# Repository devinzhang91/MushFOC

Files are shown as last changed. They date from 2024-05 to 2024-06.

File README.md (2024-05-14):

# MushFOC
A simple FOC with stm32 hal project. With PCB schematic and Python.
Reference from [CawFOC](https://github.com/GUAIK-ORG/CawFOC) and [DengFOC](https://github.com/ToanTech/DengFOC_Lib)

## STM32
- STM32G0 series, Flash 64KB and Ram 8KB.
- Control with I2C or UART (more?).
- HAL library.
- FREERTOS.

## PCB
- MCU: STM32G031F8
- Driver: DRV8313
- Current Sensor: INA180
- Angle Sensor: AS5600
- Reserve peripherals: SSD1306(OLED) MPU6050(Gyroscope)

## Python
- With smbus tools

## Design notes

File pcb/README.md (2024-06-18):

# MushFOC
A simple FOC with PCB project. 

There are some BUGs in TinyFoc_v1 SCH file, such as: 
- The direction of the LED is reversed.(BUT IT WORK!)

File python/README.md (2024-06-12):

# MushFOC
A simple FOC with stm32 hal project. Here are python control scripts. Using smbus packages.

-

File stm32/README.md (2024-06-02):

# MushFOC
A simple FOC with stm32 hal project.
- STM32G0 series, Flash 64KB and Ram 8KB.
- Control with I2C or UART (more?).
- HAL library.
- FREERTOS.

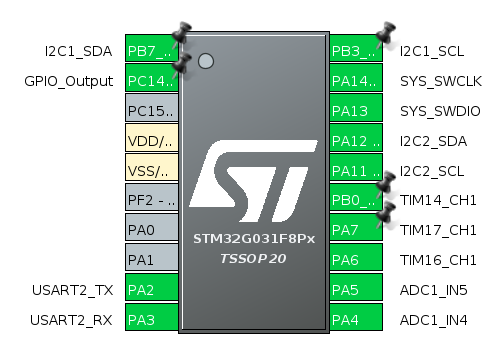
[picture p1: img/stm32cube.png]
stm32cubeMX


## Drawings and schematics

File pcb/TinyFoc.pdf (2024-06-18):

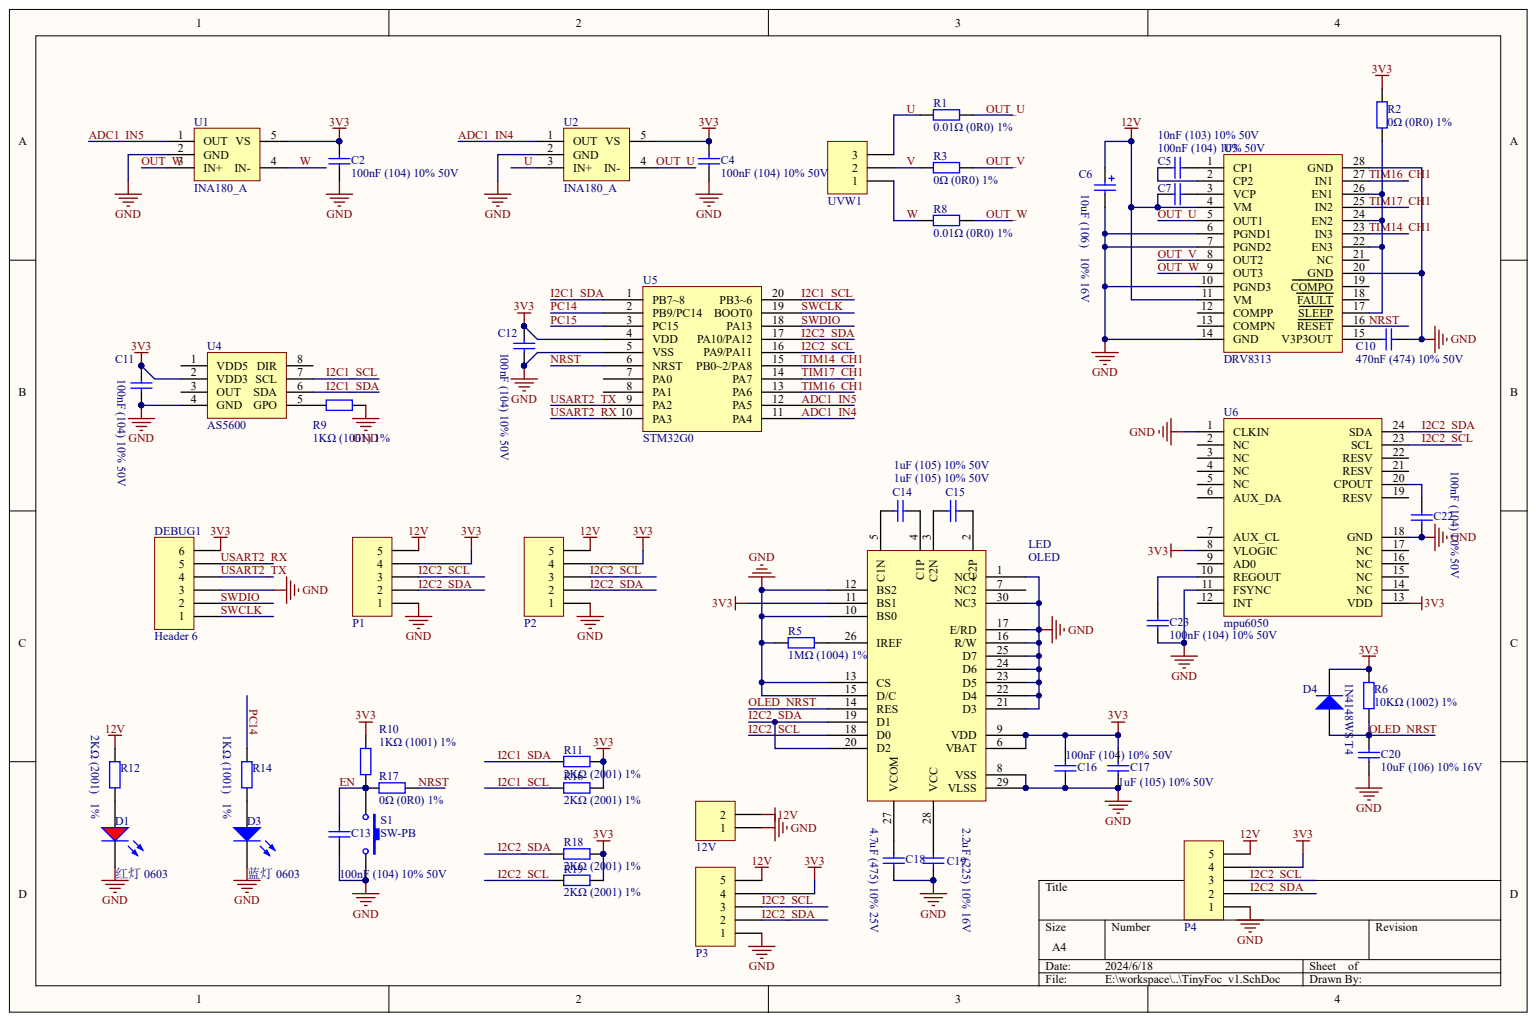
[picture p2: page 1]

OUT_V | 8

1 1
BS0 10

R5 | IREF 26

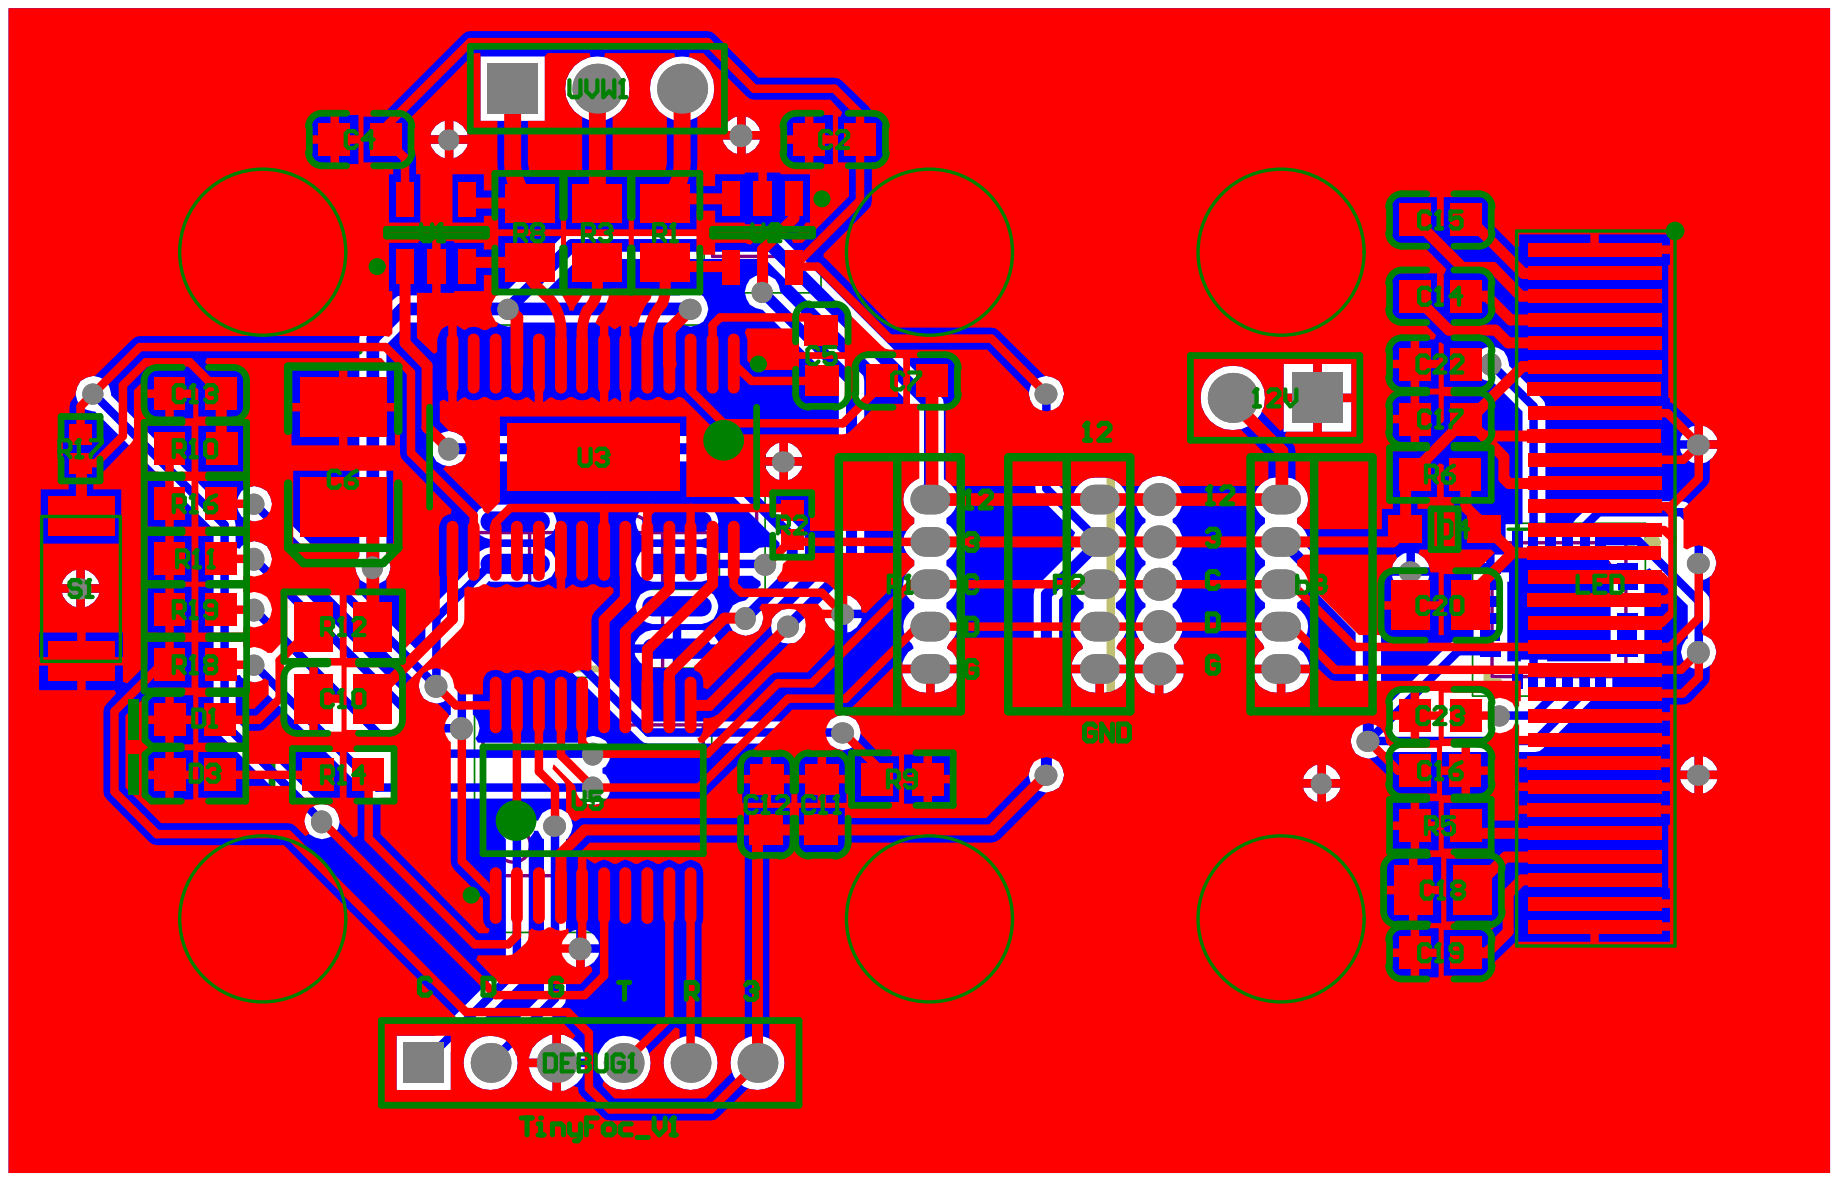
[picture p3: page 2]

Comment | Description | Designator | Footprint | LibRef | Quantity
Header 2 | 接插件 | 12V | HDR2X1_A | Header 2 | 1
100nF (104) 10% 50V | 贴片电容 | C2, C4, C7, C11, C12, C13, C16, C22, C23 | 0603_C | 0603 100nF (104) 10% 50V | 9
10nF (103) 10% 50V | 贴片电容 | C5 | 0603_C | 0603 10nF (103) 10% 50V | 1
10uF (106) ¡ À 1 0% 16V | 钽电容 | C6 | CASE-B_3528 | 3528 100uF (107) 10% 6.3V | 1
470nF (474) 10% 50V | 贴片电容 | C10 | 0805_C | 0805 470nF (474) 10% 50V | 1
1uF (105) 10% 50V | 贴片电容 | C14, C15, C17 | 0603_C | 0603 1uF (105) 10% 50V | 3
4.7uF (475) 10% 25V | 贴片电容 | C18 | 0805_C | 0805 4.7uF (475) 10% 25V | 1
2.2uF (225) 10% 16V | 贴片电容 | C19 | 0603_C | 0603 2.2uF (225) 10% 16V | 1
10uF (106) 10% 16V | 贴片电容 | C20 | 0805_C | 0805 10uF (106) 10% 25V | 1
红灯 0603 | 发光二极管 | D1 | 0603_LED_S1 | 0603 红灯 | 1
蓝灯 0603 | 发光二极管 | D3 | 0603_LED_S1 | 0603 蓝灯 | 1
1N4148WS T4 | 二极管 | D4 | SOD-323 | SOD-323 1N4148WS T4 | 1
Header 6 | 接插件 | DEBUG1 | HDR6X1_A_2.0 | Header 6 | 1
OLED | OLED显示屏12864 | LED | OLED_pin30 | OLED | 1
Header 5 | 接插件-1.27 | P1, P2, P3 | HDR5_1.27_A | Header 5 | 3
Header 5 | 接插件-1.27 | P4 | HDR5_1.27_B | Header 5 | 1
0.01Ω (0R0) ¡ À 1 % | 贴片电阻 | R1, R8 | 0805_R | 0805 0Ω (0R0) 1% | 2
0Ω (0R0) ¡ À 1 % | 贴片电阻 | R2, R17 | 0402_R | 0402 0Ω (0R0) 1% | 2
0Ω (0R0) ¡ À 1 % | 贴片电阻 | R3 | 0805_R | 0805 0Ω (0R0) 1% | 1
1MΩ (1004) ¡ À 1 % | 贴片电阻 | R5 | 0603_R | 0603 1MΩ (1004) 1% | 1
10KΩ (1002) ¡ À 1 % | 贴片电阻 | R6 | 0603_R | 0603 10KΩ (1002) 1% | 1
1KΩ (1001) ¡ À 1 % | 贴片电阻 | R9, R10, R14 | 0603_R | 0603 1KΩ (1001) 1% | 3
2KΩ (2001) ¡ À 1 % | 贴片电阻 | R11, R16, R18, R19 | 0603_R | 0603 2KΩ (2001) 1% | 4
2KΩ (2001) ¡ À 1 % | 贴片电阻 | R12 | 0805_R | 0805 2KΩ (2001) 1% | 1
SW-PB | 微动开关 | S1 | SW_PB2_3*5 | SW-PB | 1
INA180_A | 电流检测 | U1, U2 | SOT23 | INA180_A | 2
DRV8313 | 无刷电机驱动芯片 | U3 | TSSOP-28p | DRV8313 | 1
AS5600 | 磁编码器 | U4 | SOP-8N | AS5600 | 1
STM32G0 | STM32单片机20引脚 | U5 | STM8S103 | STM32G0 | 1
mpu6050 | | U6 | QFN50P400X400X80_HS-25N | mpu6050 | 1
Header 3 | 接插件 | UVW1 | HDR3X1_A | Header 3 | 1

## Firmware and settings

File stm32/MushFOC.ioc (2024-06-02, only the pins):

Mcu.UserName=STM32G031F8Px
PA13.Signal=SYS_SWDIO
PA14-BOOT0.Signal=SYS_SWCLK
PA2.Signal=USART2_TX
PA3.Signal=USART2_RX
PA4.Signal=ADC1_IN4
PA5.Signal=ADC1_IN5
PA6.Signal=S_TIM16_CH1
PA7.Signal=S_TIM17_CH1
PB1.Signal=S_TIM14_CH1
PB6.Signal=I2C1_SCL
PB7.Signal=I2C1_SDA

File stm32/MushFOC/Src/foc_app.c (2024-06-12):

/*
 * @Author: devinzhang@gmail.com
 * @Date: 2024-05-03 15:14:43
 * @LastEditors: DevinZhang91
 * @LastEditTime: 2024-05-03 15:14:43
 * @Description: Modified according to CAW FOC project https://github.com/GUAIK-ORG/CawFOC
 */
#include <foc_app.h>
#include "usart.h"

#define _PI 3.141592653589793f
uint8_t buff[16];

void FOC_APP_Init(FOC_APP_T *hfoc_app){
	hfoc_app->target_angle = 0.0f;
	hfoc_app->target_velocity = 0.0f;
	hfoc_app->target_current = 0.0f;
	hfoc_app->max_output_angle = FOC_DEFAULT_MAX_OUTPUT_ANGLE;
	hfoc_app->max_zero_angle = FOC_DEFAULT_MAX_ZERO_ANGLE;
	hfoc_app->min_zero_angle = FOC_DEFAULT_MIN_ZERO_ANGLE;
	hfoc_app->max_output_velocity = FOC_DEFAULT_MAX_OUTPUT_VELOCITY;
	hfoc_app->max_output_current = FOC_DEFAULT_MAX_OUTPUT_CURRENT;
	hfoc_app->accumulated_heat_threshold_roatio = FOC_DEFAULT_ACCUMULATED_THRESHOLD_ROATIO;
}

void FOC_CheckCurrentOverflow(){

}

// 测试闭环速度控制
void Foc_TestVelocity(FOC_T *hfoc,
					  LOWPASS_FILTER_T *hfilter_velocity,
					  PID_T *hpid_velocity,
					  float target_velocity) {
  float sensor_velocity = hfoc->Sensor_GetVelocity();
  sensor_velocity = LOWPASS_FILTER_Calc(hfilter_velocity, hfoc->dir * sensor_velocity);
  PID_Set(hpid_velocity, 0.001, 0.01, 0, 0, 20);
  FOC_SetTorque(hfoc,
		  	  	PID_Calc(hpid_velocity, (target_velocity - sensor_velocity) * 180 / _PI),
				FOC_ElectricalAngle(hfoc));
}

// 测试闭环位置控制和力矩控制
void Foc_TestAngle(FOC_T *hfoc,
				   PID_T *hpid_angle,
				   float target_angle) {
  float sensor_angle = hfoc->Sensor_GetAngle();
  // float Kp = 0.133;
  // 位置控制
  PID_Set(hpid_angle, 0.1, 0, 0, 0, 20);
  FOC_SetTorque(hfoc,
                PID_Calc(hpid_angle, (target_angle - hfoc->dir * sensor_angle) * 180 / _PI),
                FOC_ElectricalAngle(hfoc));
  // 力矩控制
  // FOC_SetTorque(hfoc, angle, FOC_CloseloopElectricalAngle(hfoc));
}

/************************************************电流反馈力矩环***************************************************/
//电流力矩环
void Foc_SetCurrentTorque(FOC_T *hfoc,
						  LOWPASS_FILTER_T *hfilter_current,
						  PID_T *hpid_current,
						  float target_current) {
	float Iq = FOC_GetCurrent(hfoc);
	Iq = LOWPASS_FILTER_Calc(hfilter_current, Iq);
	float t_Iq = PID_Calc(hpid_current, (target_current - Iq));
	FOC_SetTorque(hfoc,
				  t_Iq,
				  FOC_ElectricalAngle(hfoc));
	sprintf(buff, "%d %d\n", (int)(Iq*1000.0f), (int)(t_Iq*10.0f) );
	HAL_UART_Transmit_DMA(&huart2, (uint8_t *)buff, strlen(buff));
}

// 测试电流闭环速度控制
void Foc_TestCurrentVelocity(FOC_T *hfoc,
							 LOWPASS_FILTER_T *hfilter_current,
							 LOWPASS_FILTER_T *hfilter_velocity,
							 PID_T *hpid_current,
							 PID_T *hpid_velocity,
							 float target_velocity) {

  // 测试用例的pid
  PID_Set(hpid_current, 0.2, 0.01, 0, 100000, 6);
  PID_Set(hpid_velocity, 0.01, 0.01, 0, 100000, hfoc->voltage_power_supply / 2);

  float sensor_velocity = hfoc->Sensor_GetVelocity();
  sensor_velocity = LOWPASS_FILTER_Calc(hfilter_velocity, hfoc->dir * sensor_velocity);
  float target_current = PID_Calc(hpid_velocity, (target_velocity - sensor_velocity)*180/_PI);
  Foc_SetCurrentTorque(hfoc,
		  	  	  	   hfilter_current,
					   hpid_current,
					   target_current);
}

// 测试电流闭环位置控制
void Foc_TestCurrentAngle(FOC_T *hfoc,
						  LOWPASS_FILTER_T *hfilter_current,
						  PID_T *hpid_current,
						  PID_T *hpid_angle,
						  float target_angle) {
  // 测试用例的pid
//  // foc yaw
//  PID_Set(hpid_current, 0.27, 0.01, 0.000, 100000, hfoc->voltage_power_supply / 2);
//  PID_Set(hpid_angle, 0.4, 0.9, 0.009, 100000, 20);
  // foc pitch
  PID_Set(hpid_current, 0.13, 0.06, 0.000, 100000, hfoc->voltage_power_supply / 2);
  PID_Set(hpid_angle, 0.62, 0.95, 0.004, 100000, 30);

  float sensor_angle = hfoc->Sensor_GetAngle();
//  sprintf(buff, "%d\n", (int)(sensor_angle*1000.0f));
//  HAL_UART_Transmit_DMA(&huart2, (uint8_t *)buff, strlen(buff));
  float target_current = PID_Calc(hpid_angle, (target_angle - hfoc->dir * sensor_angle)*180/_PI);
  Foc_SetCurrentTorque(hfoc, hfilter_current, hpid_current, target_current);
}

// 测试电流闭环速度-位置控制
void Foc_TestCurrentVelocityAngle(FOC_T *hfoc,
								  LOWPASS_FILTER_T *hfilter_current,
								  LOWPASS_FILTER_T *hfilter_velocity,
								  PID_T *hpid_current,
								  PID_T *hpid_velocity,
								  PID_T *hpid_angle,
								  float target_angle) {
  // 测试用例的pid
  PID_Set(hpid_current, 0.4, 20, 0.00, 100000, hfoc->voltage_power_supply / 2);
  PID_Set(hpid_velocity, 0.1, 0.01, 0.000, 100000, 0.5);
  PID_Set(hpid_angle, 0.08, 0.01, 0.001, 100000, 10);

  float sensor_angle = hfoc->Sensor_GetAngle();
  float sensor_velocity = hfoc->Sensor_GetVelocity();
  sensor_velocity = LOWPASS_FILTER_Calc(hfilter_velocity, hfoc->dir * sensor_velocity);
  float target_velocity = PID_Calc(hpid_angle, (target_angle - hfoc->dir * sensor_angle)*180/_PI);
  float target_current = PID_Calc(hpid_velocity, (target_velocity - sensor_velocity));
  Foc_SetCurrentTorque(hfoc, hfilter_current, hpid_current, target_current);

}

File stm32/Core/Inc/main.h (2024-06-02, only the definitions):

#define I2C_SLAVE_ADDR 0x52
#define I2C_SLAVE_RX_LEN 3
#define I2C_SLAVE_TX_LEN 3
#define VDDA_APPLI          (3300UL)
#define LED_PORT            GPIOC
#define LED_PIN             GPIO_PIN_14
#define CKTIM 				64000000.0f

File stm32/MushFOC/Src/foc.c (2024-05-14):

/*
 * @Author: devinzhang@gmail.com
 * @Date: 2024-05-02 22:32:09
 * @LastEditors: DevinZhang91
 * @LastEditTime: 2024-05-02 22:32:09
 * @Description: Modified according to CAW FOC project https://github.com/GUAIK-ORG/CawFOC
 */
#include "foc.h"

#include <math.h>

#define _3PI_2 4.71238898038469f
#define _PI 3.141592653589793f
#define _1_SQRT3 0.57735026919f
#define _2_SQRT3 1.15470053838f

#define _constrain(amt, low, high) \
  ((amt) < (low) ? (low) : ((amt) > (high) ? (high) : (amt)))

// 归一化角度到 [0, 2PI]
float _normalizeAngle(float angle) {
  float a = fmod(angle, 2 * _PI);
  return a >= 0 ? a : (a + 2 * _PI);
}

// 求解电角度0专用，防止初始化的时候负角度判定为大角度，导致旋转一圈
float _electricalAngle0(FOC_T *hfoc) {
  return _normalizeAngle((float)(hfoc->dir * hfoc->pp) *
                             hfoc->Sensor_GetOnceAngle() -
                         hfoc->zero_electric_angle);
}

void _setPwm(FOC_T *hfoc, float Ua, float Ub, float Uc) {
  Ua = _constrain(Ua, 0.0f, hfoc->voltage_limit);
  Ub = _constrain(Ub, 0.0f, hfoc->voltage_limit);
  Uc = _constrain(Uc, 0.0f, hfoc->voltage_limit);

  float dc_a = _constrain(Ua / hfoc->voltage_power_supply, 0.0f, 1.0f);
  float dc_b = _constrain(Ub / hfoc->voltage_power_supply, 0.0f, 1.0f);
  float dc_c = _constrain(Uc / hfoc->voltage_power_supply, 0.0f, 1.0f);

  hfoc->Driver_SetPWM(dc_a * hfoc->pwm_period, dc_b * hfoc->pwm_period, dc_c * hfoc->pwm_period);
}

/**
 * @description: 获取闭环控制电角度数据
 * @param {FOC_T} *hfoc foc句柄
 * @return {float} 电角度值
 */
float FOC_ElectricalAngle(FOC_T *hfoc) {
  return _normalizeAngle((float)(hfoc->dir * hfoc->pp) *
                             hfoc->Sensor_GetOnceAngle() -
                         hfoc->zero_electric_angle);
}

/**
 * @description: 设置力矩
 * @param {FOC_T} *hfoc foc句柄
 * @param {float} Uq 力矩值
 * @param {float} angle_el 电角度
 * @return {*}
 */
void FOC_SetTorque(FOC_T *hfoc, float Uq, float angle_el) {
  Uq = _constrain(Uq, -hfoc->voltage_power_supply / 2,
                  hfoc->voltage_power_supply / 2.0);
  float Ud = 0;
  angle_el = _normalizeAngle(angle_el);

  // Park逆变换
  float Ualpha = -Uq * sin(angle_el);
  float Ubeta = Uq * cos(angle_el);

  // Clark逆变换
  float Ua = Ualpha + hfoc->voltage_power_supply / 2.0;
  float Ub =
      (sqrt(3) * Ubeta - Ualpha) / 2.0 + hfoc->voltage_power_supply / 2.0;
  float Uc =
      (-Ualpha - sqrt(3) * Ubeta) / 2.0 + hfoc->voltage_power_supply / 2.0;
  _setPwm(hfoc, Ua, Ub, Uc);
}

/**
 * @description: FOC控制初始化
 * @param {FOC_T} *hfoc foc句柄
 * @param {float} pwm_period PWM的重装载值
 * @param {float} voltage 电源电压值
 * @param {int} dir 方向
 * @param {int} pp 极对数
 * @return {*}
 */
void FOC_Init(FOC_T *hfoc, float pwm_period, float voltage, int dir, int pp) {
  (void *)memset((void *)hfoc, 0, sizeof(FOC_T));
  hfoc->pwm_period = pwm_period;
  // 配置电源电压和限压
  hfoc->voltage_power_supply = voltage;
  hfoc->voltage_limit = voltage;
  // 配置方向和极对数
  hfoc->dir = dir;
  hfoc->pp = pp;
}

/**
 * @description: FOC紧急停止，释放PWM输出。
 * @param {FOC_T} *hfoc foc句柄
 * @return {*}
 */
void FOC_Abort(FOC_T *hfoc){
  // 配置电源电压和限压
  hfoc->voltage_power_supply = 0.0f;
  hfoc->voltage_limit = 0.0f;
  hfoc->Driver_SetPWM(0, 0, 0);
}

/**
 * @description: 设置电压限制
 * @param {FOC_T} *hfoc foc句柄
 * @param {float} v 电压值
 * @return {*}
 */
void FOC_SetVoltageLimit(FOC_T *hfoc, float v) { hfoc->voltage_limit = v; }

/**
 * @description: 编码器零位较准（需要配置传感器相关函数指针）
 * @param {FOC_T} *hfoc foc句柄
 * @return {*}
 */
void FOC_AlignmentSensor(FOC_T *hfoc) {
  // 较准0位电角度
  if (hfoc->Sensor_GetAngle && hfoc->Sensor_GetOnceAngle) {
	//起劲
    FOC_SetTorque(hfoc, 3, _3PI_2);
	//等待转至对应角度， 更新角度
    hfoc->System_Delay(1000);
    hfoc->zero_electric_angle = _electricalAngle0(hfoc);
	//松劲
    FOC_SetTorque(hfoc, 0, _3PI_2);
    hfoc->Sensor_Update();
  }
}


/**
 * @description: 通过Ia,Ib,Ic计算Iq,Id(目前仅输出Iq)
 * @param {FOC_T} *hfoc foc句柄
 * @param {float} current_u 电流值
 * @param {float} current_v 电流值
 * @param {float} angle_el 电角度
 * @return {float} Iq值
 */
float _calIqId(float current_u, float current_v, float angle_el) {
  float I_alpha=current_u;
  float I_beta = _1_SQRT3 * current_u + _2_SQRT3 * current_v;

  float ct = cos(angle_el);
  float st = sin(angle_el);
  //float I_d = I_alpha * ct + I_beta * st;
  float I_q = I_beta * ct - I_alpha * st;
  return I_q;
}

/**
 * @description: 电流读取
 * @param {FOC_T} *hfoc foc句柄
 * @return {float}  Iq值
 */
float FOC_GetCurrent(FOC_T *hfoc) {
  // 读取电流，这里假设电流传感器的数据是Iu,Iv
  float current_uv[2];
  hfoc->Sensor_GetPhaseCurrents(current_uv, 2);
  float _electricalAngle = FOC_ElectricalAngle(hfoc);
  float Iq = _calIqId(current_uv[0], current_uv[1], _electricalAngle);
  return Iq;  
}

/**
 * @description: 绑定用于延时ms的函数
 * @param {FOC_T} *hfoc foc句柄
 * @param {FUNC_SENSOR_GET_ONCE_ANGLE} s 函数指针
 * @return {*}
 */
void FOC_Bind_Delay(FOC_T *hfoc, FUNC_DELAY t) {
  hfoc->System_Delay = t;
}

/**
 * @description: 绑定用于获取单圈弧度值的函数（0 - 6.28）
 * @param {FOC_T} *hfoc foc句柄
 * @param {FUNC_SENSOR_GET_ONCE_ANGLE} s 函数指针
 * @return {*}
 */
void FOC_Bind_SensorGetOnceAngle(FOC_T *hfoc, FUNC_SENSOR_GET_ONCE_ANGLE s) {
  hfoc->Sensor_GetOnceAngle = s;
}

/**
 * @description: 绑定用于获取累计弧度值的函数
 * @param {FOC_T} *hfoc foc句柄
 * @param {FUNC_SENSOR_GET_ANGLE} s 函数指针
 * @return {*}
 */
void FOC_Bind_SensorGetAngle(FOC_T *hfoc, FUNC_SENSOR_GET_ANGLE s) {
  hfoc->Sensor_GetAngle = s;
}

/**
 * @description: 绑定用于更新计数值相关的函数
 * @param {FOC_T} *hfoc foc句柄
 * @param {FUNC_SENSOR_UPDATE} s 函数指针
 * @return {*}
 */
void FOC_Bind_SensorUpdate(FOC_T *hfoc, FUNC_SENSOR_UPDATE s) {
  hfoc->Sensor_Update = s;
}

/**
 * @description: 绑定用户获取速度值得函数
 * @param {FOC_T} *hfoc foc句柄
 * @param {FUNC_SENSOR_GET_VELOCITY} s 函数指针
 * @return {*}
 */
void FOC_Bind_SensorGetVelocity(FOC_T *hfoc, FUNC_SENSOR_GET_VELOCITY s) {
  hfoc->Sensor_GetVelocity = s;
}

/**
 * @description: 绑定输出PWM函数
 * @param {FOC_T} *hfoc foc句柄
 * @param {FUNC_SENSOR_GET_VELOCITY} d 函数指针
 * @return {*}
 */
void FOC_Bind_DriverSetPWM(FOC_T *hfoc, FUNC_DRIVER_SET_PWM d) {
  hfoc->Driver_SetPWM = d;
}

/**
 * @description: 绑定获取电流函数
 * @param {FOC_T} *hfoc foc句柄
 * @param {FUNC_SENSOR_GET_CURRENT} s 函数指针
 * @return {*}
 */
void FOC_Bind_SensorGetPhaseCurrents(FOC_T *hfoc, FUNC_SENSOR_GET_PHASECURRENTS s) {
  hfoc->Sensor_GetPhaseCurrents = s;
}

/**
 * @description: 更新传感器数据
 * @param {FOC_T} *hfoc foc句柄
 * @return {*}
 */
void FOC_SensorUpdate(FOC_T *hfoc) { hfoc->Sensor_Update(); }

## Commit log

2024-05-14 [update] upload stm32 project.
2024-06-02 [update] Add FOC_APP_T to story foc params. Add WatchDogTask to prevent current overload.
    [MushFOC.ioc, app_freertos.c, foc_app.c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]
2024-06-12 [update] 新增输出最大速度和最大电流等设置，调整了PID参数以适合不同方向的负载。
2024-06-13 [update] 修改输入角度，当前输入角度的范围[-180, 180]
2024-06-18 [update] add pcb files.
    [TinyFoc_v1.PcbDoc, TinyFoc_v1.SchDoc]

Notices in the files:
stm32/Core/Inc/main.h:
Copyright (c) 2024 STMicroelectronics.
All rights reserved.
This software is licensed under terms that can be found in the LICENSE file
